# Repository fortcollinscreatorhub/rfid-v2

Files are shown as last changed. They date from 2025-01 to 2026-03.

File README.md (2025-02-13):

# What is this repository?

An RFID reader solution for Fort Collins Creator Hub. The Hub uses RFID readers
on external doors to allow people into the building, and to control
access-to/use-of equipment.

This version of the RFID reader:
* Was developed by Stephen Warren; v1 was by Steve Undy.
* The PCB relies on COTS (Commercial Off-The-Shelf) components where possible,
  to reduce circuit complexity.
* The PCB uses through-hole construction, to make it easier for arbitary people
  to construct.
* Management of the reader is intended to be easier:
  * The PCB has an LCD for status display.
  * WiFi AP mode is enabled when STA mode cannot connect.
  * A web interface is always available for management.
    This may be password protected.
* The software configuration code ("connection manager") is intended to be
  modular and re-usable by other projects. It may be moved into a shared git
  submodule one day.

# How to clone this repository

This project uses git submodules, unfortunately. To clone the repository, run:

```shell
git clone --recurse-submodules https://github.com/fortcollinscreatorhub/rfid-v2
```

If you wish to push back to the github repo, you probably want to clone with
`ssh`, or edit `.git/config` to use ssh URLs after cloning, e.g.:

```shell
git clone --recurse-submodules git@github.com:fortcollinscreatorhub/rfid-v2
```

Or after cloning:

```shell
vi .git/config
```

Even if you clone using the ssh URL, you'll still need to edit the remote
definition for each submodule after the initial clone operation.

# PCB (circuit board)

See the [PCB README](pcb/README.md).

# Software (code)

See the [code README](code/README.md).

# Mounting Boxes

See the [mounting boxes README](mounting-boxes/README.md).

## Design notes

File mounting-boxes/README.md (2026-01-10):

# Mounting box designs

## For equipment

See the [equipment box README](equipment/README.md).

## 3D-printed 

A 3D printed box, as used on our electronics "locker".
See [3D printed box README](3d-printed/README.md).

## For doors

Not yet!

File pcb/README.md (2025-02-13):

# PCB (circuit board)

The PCB was developed using KiCAD 7.0.11 under Ubuntu.

Prototype versions of the PCB were manufactured by
[OSHPARK](https://oshpark.com/). The KiCAD PCB file was uploaded directly, as
opposed to exporting Gerber files, etc.

A production run of the PCB was manufactured by [JLCPCB](https://jlcpcb.com/), using the
Gerber files in directory `gerber-20250210/`.

Read the [Bill Of Materials](BOM.txt).

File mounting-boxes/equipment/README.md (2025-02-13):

# Mounting box for equipment

A design for a box to contain the PCB, and to attach to a piece of equipment.
It's designed to screw into any of:
* A 4" weather-proof box. Good fit. E.g.
  https://www.homedepot.com/p/Commercial-Electric-2-Gang-Metallic-Weatherproof-Box-with-5-3-4-in-Holes-Gray-WDB575G/300846319
* A 2-gang electrical box. Overhangs a bit. E.g.
  https://www.homedepot.com/p/Southwire-4-in-W-x-2-1-8-in-D-Steel-Metallic-2-Gang-Square-Switch-Box-Six-1-2-in-KO-s-Two-3-4-KO-s-and-Four-CKO-s-MGSB-2-UPC/324509229
* A 4" electrical box. Overhangs a bit. E.g.
  https://www.homedepot.com/p/Steel-City-4-in-30-3-cu-in-Metallic-Square-Box-521711234EW-25R/202590467

The design uses [OpenSCAD](https://openscad.org/). Run `render-2d.sh` (under
Linux or WSL2) to render the result.

The layers should be attached using barrel screws (also known as binding
posts, chicago screws, sex screws, and probably other names). Insert these
from the back before mounting to the electrical box. For example:
https://www.amazon.com/dp/B0D5HP8TXD (M4x12mm, 5x20mm).

You could use M3/4 metal inserts or other nuts/bolts if you want. If so,
you'll need to adjust barrel_nut_r/barrel_screw_r in the .scad file to match,
and perhaps also adjust which layers use barrel_nut_holes vs.
barrel_screw_holes.

Layer -1 should be made from thin acrylic; perhaps 1mm, perhaps 3mm. Layers 0,
1, 3, 4 should be made from 3mm acrylic. Layer 2 should be made from 6mm
acrylic to save time, but can also be made from 3mm acrylic if you make more
copies. For layer 2, most likely you will need 2 6mm copies and 1 3mm copy, or
5 3mm copies.

Layer -1 allows the box to seal completely against the box it's screwed to,
since the ends of the barrel nuts stick out a fair way from the box.
Alternatively, you could glue together layers 0 and 1, then move the barrel nut
cutouts to layer 0...

Layers -1 and 0 should be screwed onto the electrical box. Other layers will be
held on by the barrel screws.

The RFID "cage" pieces should be glued into layer 4 using Weldon #4:
https://www.amazon.com/dp/B00TCUJ7A8.

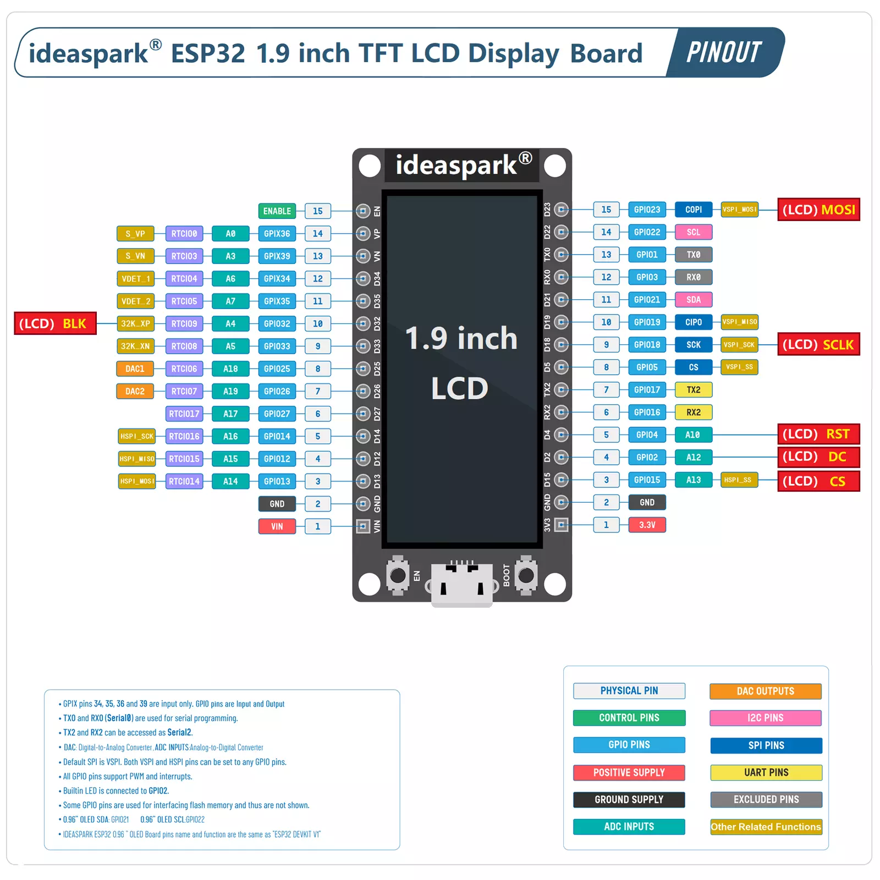
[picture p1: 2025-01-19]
pcb/datasheets-etc/esp32-lcd-190-pinout.webp

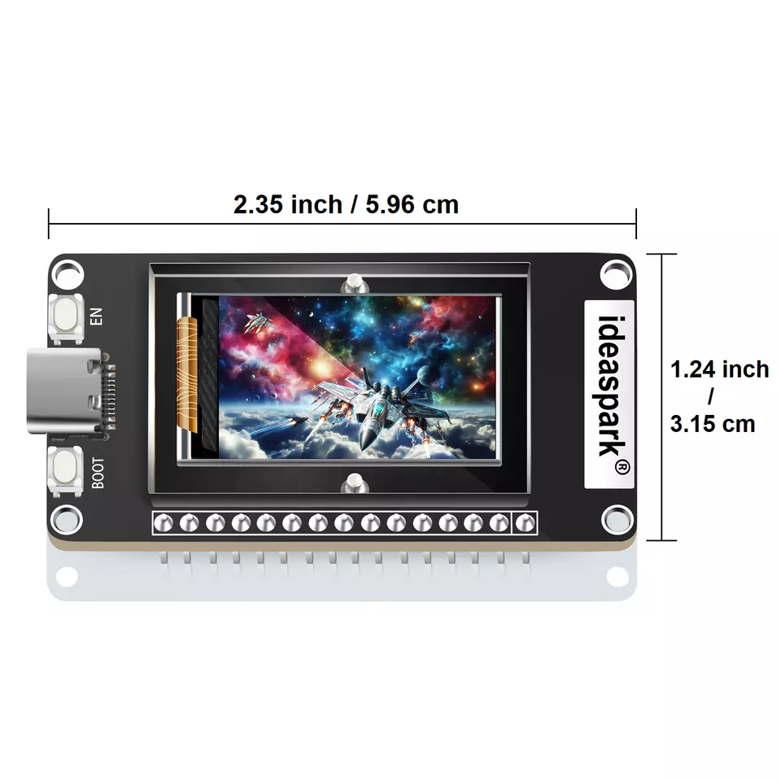
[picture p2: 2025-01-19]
pcb/datasheets-etc/esp32-lcd-114-physical.webp

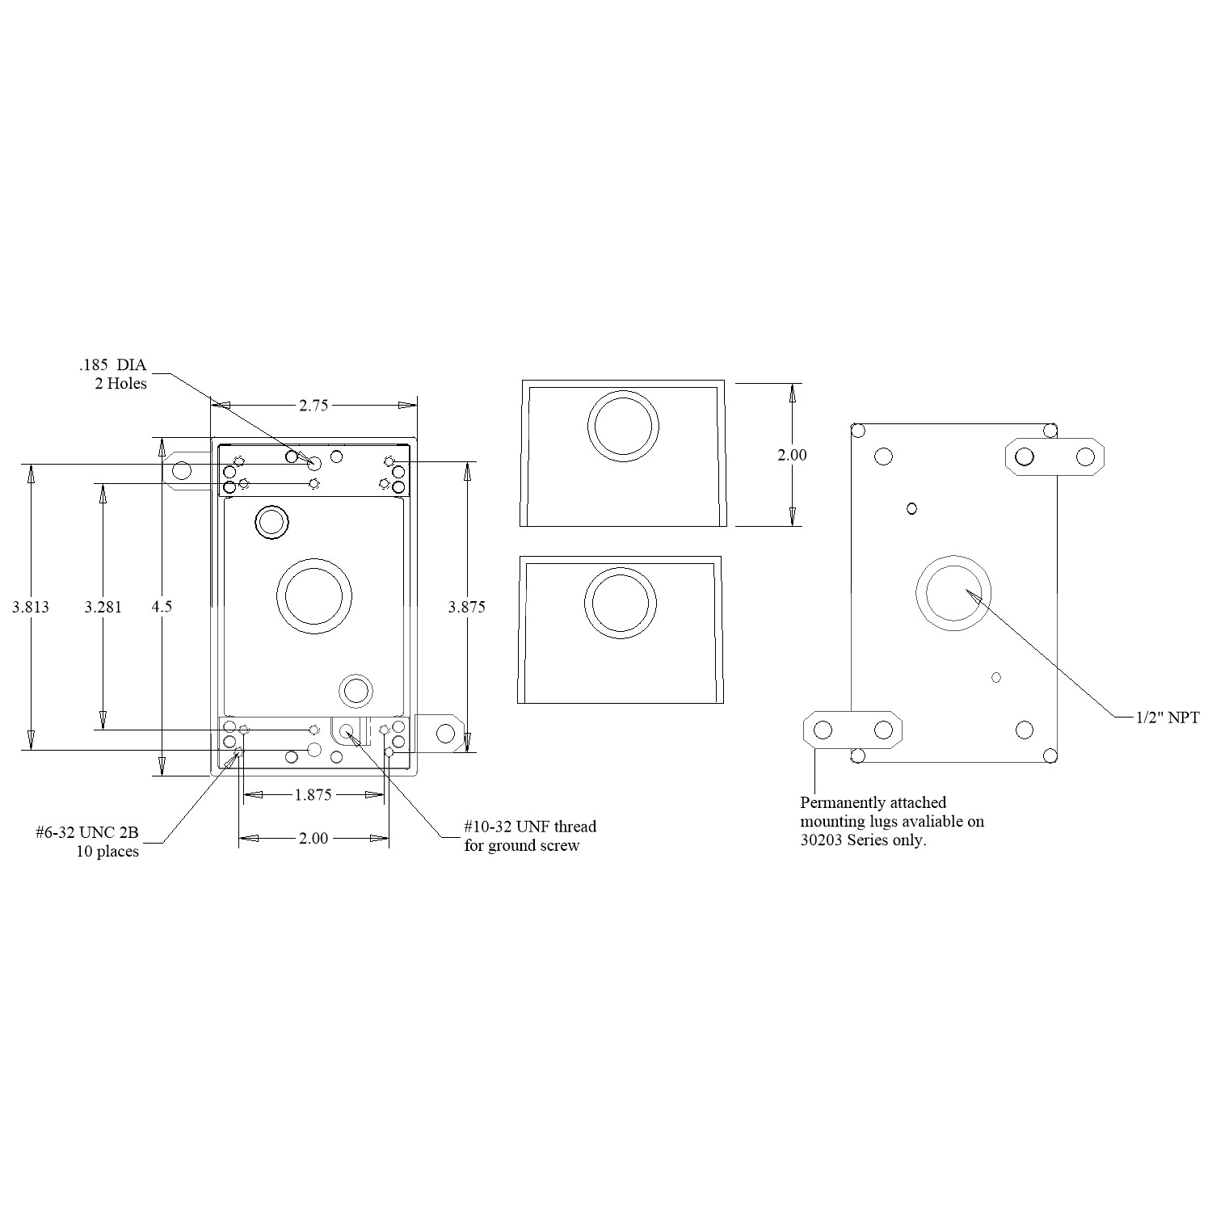
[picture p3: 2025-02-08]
mounting-boxes/electrical-box-drawings/1-gang-waterproof-box-mulberry-metal.jpg

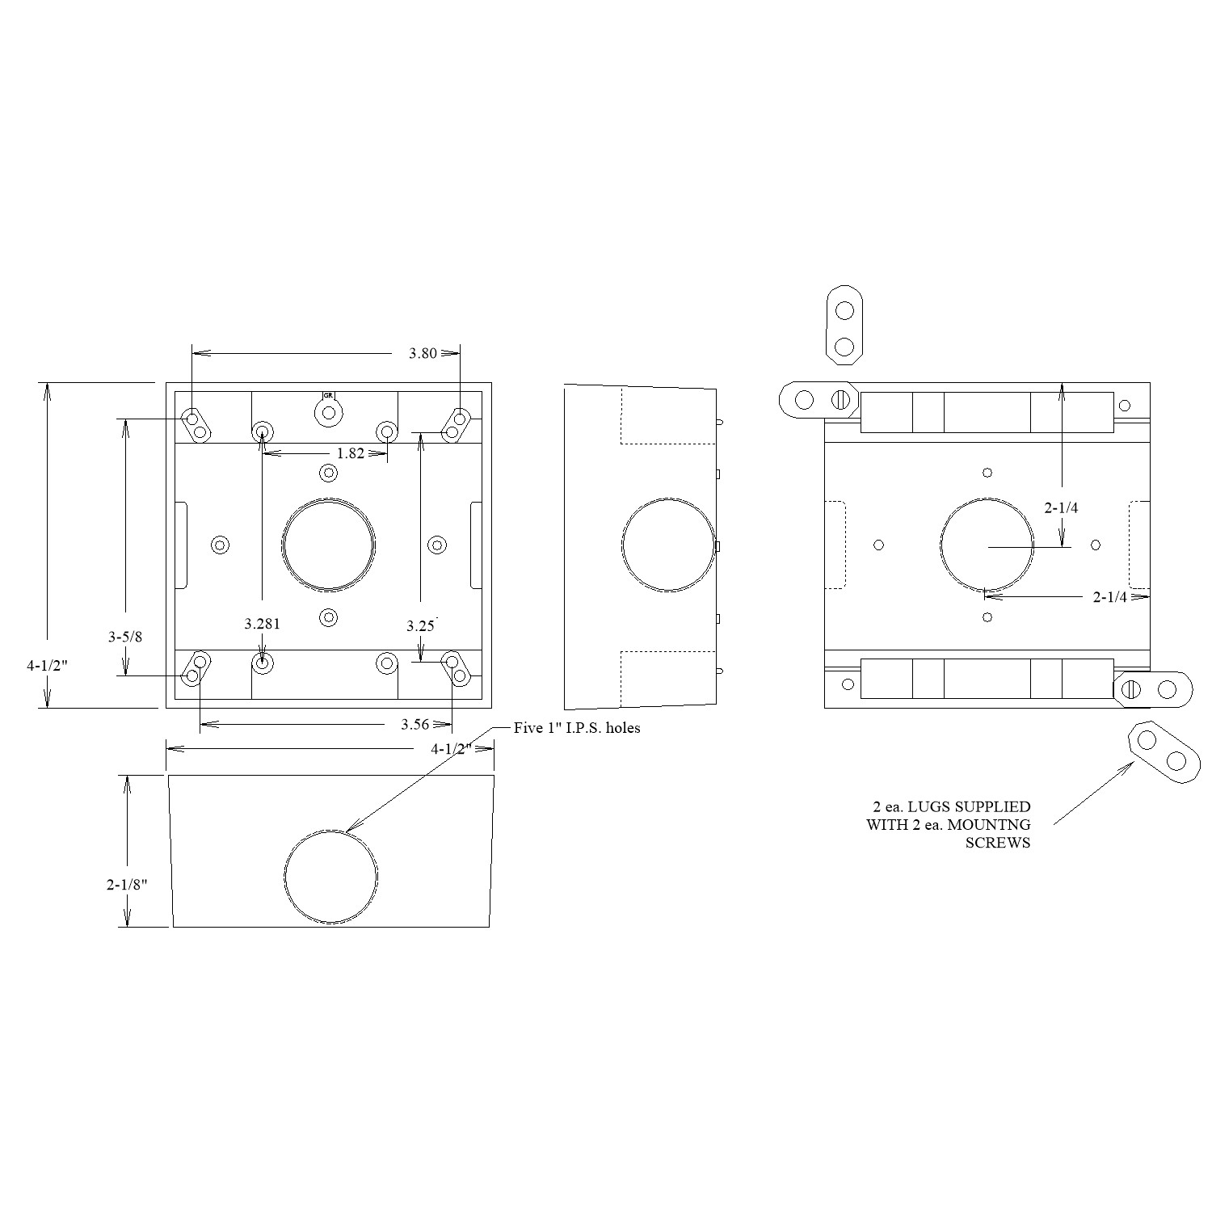
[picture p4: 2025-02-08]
mounting-boxes/electrical-box-drawings/2-gang-waterproof-box-mulberry-metal.jpg

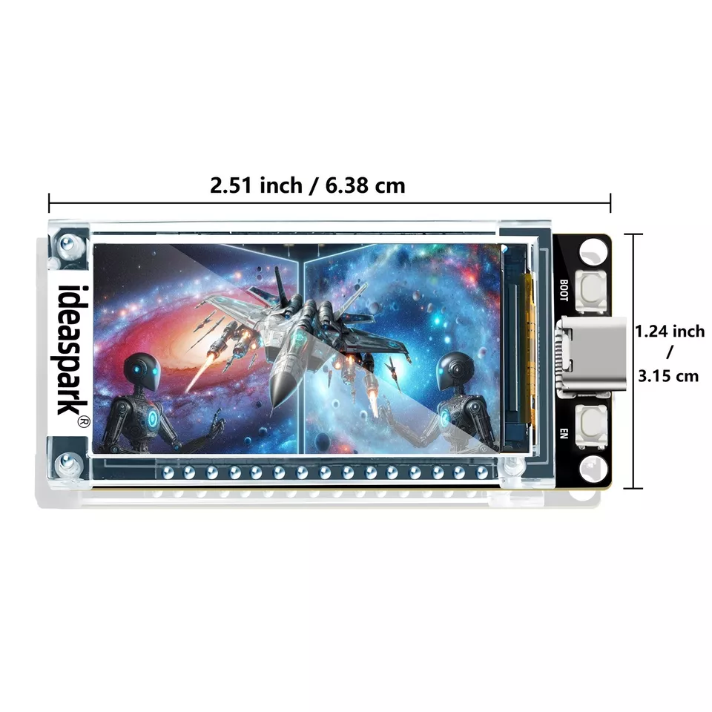
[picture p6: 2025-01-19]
pcb/datasheets-etc/esp32-lcd-190-physical.webp

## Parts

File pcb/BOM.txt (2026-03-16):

U1
    ideaspark® ESP32 Development Board 1.14 inch 135x240 LCD Display,CH340,WiFi+BL
    https://www.ebay.com/itm/176446899270
    ebay seller: https://www.ebay.com/str/ideaspark
    https://www.amazon.com/dp/B0D7S7YQMC
    https://www.aliexpress.us/item/3256807079419720.html

    Alternative (change runtime LCD config):
    ideaspark® ESP32 Development Board 16MB 1.9 in 170x320 LCD Display,CH340,WiFi+BL
    https://www.ebay.com/itm/176425903544
    ebay seller: https://www.ebay.com/str/ideaspark
    https://www.amazon.com/dp/B0D6QXC813
    https://www.aliexpress.us/item/3256806995121078.html

U2
    RDM6300
    HiLetgo RDM6300 125 KHZ EM4100 RFID Card Read Module UART Serial Output for Arduino
    https://www.amazon.com/dp/B00HGB9TOE
    https://www.aliexpress.us/item/3256803401542028.html
    (Many others sell the exact same item on all sites)

U3
    TTGO LILYGO T-Display V1.1
    https://www.amazon.com/dp/B099MPFJ9M
    https://lilygo.cc/en-us/products/t-display?variant=42159376466101

    MELIFE ESP32 Development Board, 16MB Integrated LCD WiFi Kit, 1.14 Inch 135x240 TFT LCD Display,
    https://www.amazon.com/dp/B0FB94RC47

Q1
    PN2222A TO92 (or probably many other NPN BJTs)
    https://www.mouser.com/ProductDetail/onsemi-Fairchild/PN2222ABU?qs=UMEuL5FsraBJOIjLOc%2FtCA%3D%3D
    https://www.digikey.com/en/products/detail/stmicroelectronics/PN2222A/603431 (no longer manfucatured)
    https://www.digikey.com/en/products/detail/onsemi/PN2222ABU/6534
    https://www.amazon.com/dp/B0C1V82313

D1
    1N4001 (or probably many other diodes)
    https://www.mouser.com/ProductDetail/Diotec-Semiconductor/1N4001?qs=OlC7AqGiEDlll8NA510wmA%3D%3D
    https://www.digikey.com/en/products/detail/diotec-semiconductor/1N4001/13164614
    https://www.amazon.com/dp/B0C1V6Y8ND

R1
    1K resistor (any; low power)
    https://www.mouser.com/ProductDetail/SEI-Stackpole/RNMF14FTC1K00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 (1/4W 1%)
    https://www.digikey.com/en/products/detail/stackpole-electronics-inc/RNMF14FTC1K00/2617302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 (1/4W 1%)
    https://www.amazon.com/ALLECIN-Metal-Film-Resistor-Kit/dp/B0CDWVLTM1 (1/4W 1%)
    https://www.amazon.com/ALLECIN-8W-Metal-Film-Resistor/dp/B0C77TM3NR (1/8W 1%

R2
    10K resistor (any; low power)
    https://www.mouser.com/ProductDetail/SEI-Stackpole/RNMF14FTC10K0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 (1/4W 1%)
    https://www.digikey.com/en/products/detail/stackpole-electronics-inc/RNMF14FTC10K0/1683930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 (1/4W 1%)
    https://www.amazon.com/ALLECIN-Metal-Film-Resistor-Kit/dp/B0CDWVLTM1 (1/4W 1%)
    https://www.amazon.com/ALLECIN-8W-Metal-Film-Resistor/dp/B0C77TM3NR (1/8W 1%

R3
    2K2 resistor (any; low power)
    https://www.mouser.com/ProductDetail/SEI-Stackpole/RNMF14FTC2K20?qs=FESYatJ8odLQKVeLgxWICg%3D%3D (1/4W 1%)
    https://www.digikey.com/en/products/detail/stackpole-electronics-inc/RNMF14FTC2K20/2617325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 (1/4W 1%)
    https://www.amazon.com/ALLECIN-Metal-Film-Resistor-Kit/dp/B0CDWVLTM1 (1/4W 1%)
    https://www.amazon.com/ALLECIN-8W-Metal-Film-Resistor/dp/B0C77TM3NR (1/8W 1%

R4
    3K3 resistor (any; low power)
    https://www.mouser.com/ProductDetail/SEI-Stackpole/RNMF14FTC3K30?qs=FESYatJ8odL%252B4KIkrQ9kpA%3D%3D (1/4W 1%)
    https://www.digikey.com/en/products/detail/stackpole-electronics-inc/RNMF14FTC3K30/2617342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 (1/4W 1%)
    https://www.amazon.com/ALLECIN-Metal-Film-Resistor-Kit/dp/B0CDWVLTM1 (1/4W 1%)
    https://www.amazon.com/ALLECIN-8W-Metal-Film-Resistor/dp/B0C77TM3NR (1/8W 1%

K1
    Omron G6S-2
    https://www.mouser.com/ProductDetail/Omron-Electronics/G6S-2-DC5?qs=PuRzBkp%252Brz5TA3zk18rsvQ%3D%3D
    https://www.digikey.com/en/products/detail/omron-electronics-inc-emc-div/G6S-2-DC5/333982
    https://www.amazon.com/dp/B082Z3K9BG

J1
    0.2"/5mm PCB mount screw terminal block, 2-pin
    https://www.mouser.com/ProductDetail/Phoenix-Contact/5452257?qs=iCzJi%2FIZBF6%2Fj2I2DfTHZA%3D%3D
    https://www.digikey.com/en/products/detail/phoenix-contact/5452257/4391130?s=N4IgTCBcDaIKwBY5jHA7CAugXyA
    https://www.amazon.com/gp/product/B0D1GMMTZ5

J2
    0.2"/5mm PCB mount screw terminal block, 3-pin
    https://www.mouser.com/ProductDetail/Phoenix-Contact/5452258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
    https://www.digikey.com/en/products/detail/phoenix-contact/5452258/4391131
    https://www.amazon.com/gp/product/B0D1GMMTZ5

J3
    No part; solder in the coil that comes with RDM6300.

Power supply for the RFID reader
    Meanwell APV-25-5 (25W 5V) (rather large.)
    https://www.amazon.com/dp/B00HKJ6JKE
    Meanwell APV-12-5 (12W 5V) (smaller, cheaper, and seems to work fine.)
    https://www.amazon.com/dp/B00FRBSI2E

Power supply for 12V external devices
    Meanwell APV-25-12 (25W 12V)
    https://www.amazon.com/Constant-Voltage-Switching-Supply-2100mA/dp/B00MEJTTCU

SSR for device control
    CG Solid State Relay SSR-25DA DC to AC Input 3-32VDC To Output 24-480VAC 25A Single Phase Plastic Cover…
    https://www.amazon.com/dp/B08GPJ1V2J
    (or many others)

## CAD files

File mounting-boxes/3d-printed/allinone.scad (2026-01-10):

// ==========================================
//    RFID - V2 Enclosure w/ Buck Converter
// ==========================================
// 
// This script generates a custom 3D-printable enclosure for an RFID reader,
// designed to house a controller PCB, buck converter, and DC jack in a 
// compact, modular base.
//
// All the pieces are:
// - The base. 
// -- Uses clip tabs to hold down the controller board since it doesn't have mounting holes 
// -- Screw posts for buck converter
// - The lid. W/ opening for LCD and recessed cavity for RFID antenna. 
// - A cover for the RFID antenna mounted inside the lid. Should glue over that slot.
// - A cover for the banana jack housing. I'm using the one that came w/ the power brick.
// - An external cover for the male end of DC jack that plugs into that.
// - A plug (need 2x) to cover the boot and reset buttons on the controller board

$fn = 60;

// This can help isolate rendering different modules in case you want to 
// export STL separately. If you choose "all" then everything will be rendered
// at once and you can split apart in slicer.
//
part_to_show = "all"; // Options: "base", "lid", "dc_lid", "jack_cover", "antenna_cover", "cable_clamp", "plugs", "inserts", "all", "closed", "cutaway"

// The FCCH RFID-V2 main board. Snap toggles hold it in place
pcb_width = 45.2;
pcb_length = 90.2;
pcb_thickness = 1.6;

// LM2596 generic Buck Converter
buck_width = 43;      
buck_length = 21;     
buck_hole_dist_x = 31;
buck_hole_dist_y = 16; 
buck_hole_dia = 2.0;
buck_elevation = 5;

// DC Jack Internal Compartment to securely hold the jack in place
//
dc_comp_inner_w = 15;  
dc_comp_inner_l = 33;  
dc_jack_hole = 8;   
dc_slot_size = 10.5;   

// Main board USB opening
enable_usb_slot = true;
usb_slot_width = 12;   
usb_slot_height = 6;   
usb_z_adjust = 5;    

// Layout and spacing
side_padding_x = 9.0; 
pcb_vertical_margin = 1.0; 
col_spacing = 8;        
row_spacing = 8;     
dc_jack_height = 12.25; 

// Positioning parameters for rfid antenna within lid
rfid_ant_w = 47.5; rfid_ant_l = 36.5; rfid_ant_depth = 2.25;
rfid_pos_x = 43; rfid_pos_y = 21; 

// Cutouts for main board lcd, boot and reset buttons
lcd_width = 25; lcd_height = 38;
button_diameter = 6; button_spacing = 16.5;
lcd_pos_x = 15.8; lcd_pos_y = 20;
buttons_center_x = lcd_pos_x + (lcd_width / 2); 
buttons_center_y = 11;

// Tabs holding main pc board in base
enable_mounting_tabs = true;
tab_protrusion = 10;
tab_width = 15;
tab_hole_dia = 4.5;
tab_thickness = 3.0;

// Various mounting helpers
post_diameter = 8;
pin_diameter = 5.2;
screw_hole_inner = 2.8;
screw_hole_outer = 3.4;
screw_thread_depth = 12;

// Cover for external dc power supply jack in comboniation with Jack Cover below
lock_pin_dia = 2.4;       
lock_travel_y = 3.5;
boss_w = dc_jack_hole + 10; 
// boss_h calculated in Engine
boss_depth = 4.0;         
lock_tolerance = 0.3;

// Jack Cover Settings
jack_plug_length = 26;
jack_plug_dia = 10;
jack_wire_dia = 5;
cover_wall_t = 1.6;

// Some generic dimensions
wall_thickness = 2.4;
lid_thickness = 4.0; 

internal_wall_t = 1.6; 
pcb_elevation = 5;
tolerance = 0.5;
lip_depth = 2.0;
internal_height = 18; // [UPDATED] Height reduced as requested
corner_radius = 3.0;

// DC Lid Settings
dc_lid_cap_thickness = 2.0;
dc_lid_plug_depth = 2.4; 

// Logo Insert Settings
logo_tolerance = 0.1; 

// ==========================================
//            Derived Dimensions
// ==========================================

usb_slot_x_center = wall_thickness + side_padding_x + 15.5;

// Calculate Jack Z Height Globally
jack_center_z = wall_thickness + 1.25 + (dc_jack_hole / 2);

// Calculate Boss Height to reach from Z=0 to Top Clearance
boss_h = jack_center_z + (dc_jack_hole / 2) + 3.0;

// Calculate Base Requirements
col1_w = pcb_width;
col1_l = pcb_length;

buck_rot_w = buck_length; 
buck_rot_l = buck_width;  

// DC Width (Includes LEFT and RIGHT internal walls)
dc_outer_w = dc_comp_inner_w + (internal_wall_t * 2);
dc_outer_l = dc_comp_inner_l + internal_wall_t;

// Total length of DC walls including the extension to front wall
dc_wall_total_l = dc_outer_l + pcb_vertical_margin;

col2_w = max(buck_rot_w, dc_outer_w);
col2_l = dc_outer_l + row_spacing + buck_rot_l;

req_inner_w = side_padding_x + col1_w + col_spacing + col2_w + side_padding_x;
base_req_inner_l = pcb_vertical_margin + max(col1_l, col2_l) + pcb_vertical_margin;

// 3. Final Box Dimensions
max_comp_x = max(rfid_pos_x + rfid_ant_w, lcd_pos_x + lcd_width, buttons_center_x + button_spacing/2 + button_diameter/2);
max_comp_y = max(rfid_pos_y + rfid_ant_l, lcd_pos_y + lcd_height, buttons_center_y + button_diameter/2);
lid_req_outer_w = max_comp_x + wall_thickness;
lid_req_outer_l = max_comp_y + wall_thickness;

final_outer_w = max(req_inner_w + (wall_thickness*2), lid_req_outer_w);
final_outer_l = max(base_req_inner_l + (wall_thickness*2), lid_req_outer_l); 

final_inner_w = final_outer_w - (wall_thickness*2);
final_inner_l = final_outer_l - (wall_thickness*2);


// ==========================================
//            All the modules
// ==========================================

module rounded_rect(w, l, h, r) {
    hull() {
        translate([r, r, 0]) cylinder(h=h, r=r);
        translate([w-r, r, 0]) cylinder(h=h, r=r);
        translate([w-r, l-r, 0]) cylinder(h=h, r=r);
        translate([r, l-r, 0]) cylinder(h=h, r=r);
    }
}

module pcb_snap_latch() {
    clip_w = 10; clip_t = 1.6; latch_h = pcb_elevation + pcb_thickness + 1.2;
    translate([-clip_t, -clip_w/2, 0]) cube([clip_t, clip_w, latch_h]);
    translate([0, -clip_w/2, latch_h]) rotate([-90, -90, 0]) linear_extrude(clip_w) polygon([[0,0], [0, -2], [1.5, -2], [0.8, 0], [0, 0.5]]);
}

module mounting_tab(angle_rotation) {
    gusset_height = internal_height * 0.6;
    side_gusset_thickness = 2.4; 
    rotate([0,0,angle_rotation]) {
        difference() {
            union() {
                hull() {
                    translate([-tab_width/2, 0, 0]) cube([tab_width, 0.1, tab_thickness]);
                    translate([0, tab_protrusion, 0]) cylinder(h=tab_thickness, d=tab_width);
                }
                hull() {
                    translate([-tab_width/2, 0, tab_thickness]) cube([side_gusset_thickness, 0.1, gusset_height]);
                    translate([-tab_width/2, tab_protrusion, tab_thickness]) cube([side_gusset_thickness, 0.1, 0.1]);
                }
                hull() {
                    translate([tab_width/2 - side_gusset_thickness, 0, tab_thickness]) cube([side_gusset_thickness, 0.1, gusset_height]);
                    translate([tab_width/2 - side_gusset_thickness, tab_protrusion, tab_thickness]) cube([side_gusset_thickness, 0.1, 0.1]);
                }
            }
            translate([0, tab_protrusion, -1]) cylinder(h=tab_thickness + 2, d=tab_hole_dia);
        }
    }
}

module dc_compartment_lid() {
    fit_tol = 0.15; 
    
    // Tab Settings
    tab_len = 15;
    tab_dep = 5.25;
    tab_wid = 2.5;

    union() {
        // 1. The Main Cap
        cube([dc_outer_w, dc_wall_total_l, dc_lid_cap_thickness]);
        
        // 2. The Plug
        translate([internal_wall_t + fit_tol, internal_wall_t + fit_tol, -dc_lid_plug_depth]) {
            cube([
                dc_comp_inner_w - (fit_tol*2), 
                (dc_wall_total_l - (internal_wall_t*2)) - (fit_tol*2), 
                dc_lid_plug_depth
            ]);
        }
        
        // 3. Inside Top Edge Tab
        translate([
            (dc_outer_w - tab_len) / 2,     
            dc_wall_total_l - internal_wall_t - tab_wid - fit_tol, 
            -tab_dep                        
        ])
        cube([tab_len, tab_wid, tab_dep]);
    }
}


module jack_cover() {
    // 1. Calculate Internal Dimensions
    inner_w = boss_w + (lock_tolerance * 2);
    inner_h = boss_h + (lock_tolerance * 2);
    
    // 2. Calculate Depth
    internal_depth = jack_plug_length + boss_depth;
    
    // 3. Calculate External Dimensions
    cover_w = inner_w + (cover_wall_t * 2);
    cover_l = internal_depth + cover_wall_t; // Add thickness for the back wall
    cover_h_dim = inner_h + cover_wall_t;    // Add thickness for the top wall

    // Pin Positions 
    pin_z = 3.0; 
    pin_y_offset = boss_depth / 2; 

    difference() {
        // Main Block
        cube([cover_w, cover_l, cover_h_dim]);
        
        // Internal Cavity ("The Garage")
        translate([cover_wall_t, -0.1, -0.1])
            cube([inner_w, internal_depth + 0.1, inner_h]);
            
        // Wire Slot
        translate([(cover_w/2) - (jack_wire_dia/2), internal_depth - 2, -0.1])
            cube([jack_wire_dia, cover_wall_t + 10, inner_h]);
    }
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

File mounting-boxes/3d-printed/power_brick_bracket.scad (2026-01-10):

// A mounting cover for a 12v dc power brick that's used to power the RFID latch locker
// Printed w/ PLA is fine probably. We'll see.
//

// Power Supply Dimensions
psu_length = 120.5;
psu_width  = 51.5;
psu_height = 35.0;

// Housing settings
wall_thick = 2.4;       
tolerance  = 1.0; 
corner_radius = 3.0;    // Radius of the outside vertical edges

// Mounting Tab Settings
mount_hole_dia = 3.5;       // Screw shaft size
head_dia       = 6;       // Screw head size (Counterbore)
head_depth     = 5.0;       // Depth of screw head recess
tab_stick_out  = 14.0;      // How far the tab extends out
tab_length     = 30.0;      // Width of the tab along the wall

// Input Power Cord Slot (Centered)
slot1_width = 17.0;
slot1_depth = 22.0;    

// DC Output Cord Slot (Offset)
slot2_width = 14.0;
slot2_depth = 20.0;
slot2_offset = 7;    

// Ventilation
vent_width = 4;
vent_gap = 4;

// --- Calculated Values ---
inner_l = psu_length + tolerance;
inner_w = psu_width + tolerance;
inner_h = psu_height + tolerance; 

outer_l = inner_l + (wall_thick * 2);
outer_w = inner_w + (wall_thick * 2);
outer_h = inner_h + wall_thick; 

// --- Main Render ---

difference() {
    union() {
        // 1. Main Housing Body (Rounded)
        translate([0, 0, outer_h/2])
            rounded_box(outer_l, outer_w, outer_h, corner_radius);
            
        // 2. Gusseted Tabs
        generate_pocket_tabs();
    }

    // 3. Hollow out the inside (Sharp corners for the brick)
    translate([-inner_l/2, -inner_w/2, -1])
        cube([inner_l, inner_w, inner_h + 1]);

    // 4. Slot 1: Power Cord
    translate([-outer_l/2 - 5, -slot1_width/2, -1])
        cube([wall_thick + 10, slot1_width, slot1_depth + 1]);

    // 5. Slot 2: DC Out
    // MIRRORED: Measured from the -Y edge
    translate([outer_l/2 - wall_thick - 5, -(inner_w/2) + slot2_offset, -1])
        cube([wall_thick + 10, slot2_width, slot2_depth + 1]);

    // 6. Rounded Vents
    generate_side_vents();
    generate_top_vents();
}

// --- Modules ---

module rounded_box(len, wid, hei, rad) {
    x_pos = (len/2) - rad;
    y_pos = (wid/2) - rad;
    
    hull() {
        translate([-x_pos, -y_pos, -hei/2]) cylinder(r=rad, h=hei, $fn=50);
        translate([x_pos, -y_pos, -hei/2])  cylinder(r=rad, h=hei, $fn=50);
        translate([-x_pos, y_pos, -hei/2])  cylinder(r=rad, h=hei, $fn=50);
        translate([x_pos, y_pos, -hei/2])   cylinder(r=rad, h=hei, $fn=50);
    }
}

module generate_pocket_tabs() {
    translate([0, -outer_w/2, 0]) 
        make_pocket_tab();

    translate([0, outer_w/2, 0]) 
        rotate([0,0,180]) make_pocket_tab();
}

module make_pocket_tab() {
    sink = 2.0; 
    gusset_height = tab_stick_out;
    base_h = 2.0; 
    
    difference() {
        // 1. Solid Ramp
        hull() {
            translate([-tab_length/2, -tab_stick_out, 0])
                cube([tab_length, tab_stick_out + sink, base_h]); 
            
            translate([-tab_length/2, sink, gusset_height + base_h])
                cube([tab_length, 0.1, 0.1]);
        }
        
        // 2. Screw Shaft Slot
        hull() {
            translate([-2, -tab_stick_out/2, -1])
                cylinder(h=gusset_height + 5, d=mount_hole_dia, $fn=30);
            translate([2, -tab_stick_out/2, -1])
                cylinder(h=gusset_height + 5, d=mount_hole_dia, $fn=30);
        }

        // 3. Counterbore Pocket
        hull() {
            translate([-2, -tab_stick_out/2, base_h + head_depth]) 
                cylinder(h=gusset_height, d=head_dia, $fn=30);
            translate([2, -tab_stick_out/2, base_h + head_depth]) 
                cylinder(h=gusset_height, d=head_dia, $fn=30);
            
            translate([-2, -tab_stick_out/2, head_depth])
                cylinder(h=1, d=head_dia, $fn=30);
            translate([2, -tab_stick_out/2, head_depth])
                cylinder(h=1, d=head_dia, $fn=30);
        }
    }
}

module generate_side_vents() {
    start_height = tab_stick_out + 4; 
    safe_length = inner_l - (2 * corner_radius) - 10;
    
    count = floor(safe_length / (vent_width + vent_gap));
    start_x = -((count * (vent_width + vent_gap)) / 2) + (vent_width/2);
    
    r = vent_width / 2;
    h_vent = inner_h - start_height - 5;
    
    for (i = [0 : count-1]) {
        x_pos = start_x + (i * (vent_width + vent_gap));
        
        // Use hull of 2 cylinders to make a pill shape (vertical slot)
        // Oriented to cut through Y axis
        translate([x_pos + r, 0, 0]) { // Shift X by radius to center the hull
            hull() {
                // Bottom of slot
                translate([0, -outer_w/2 - 5, start_height + r])
                    rotate([-90, 0, 0])
                    cylinder(r=r, h=outer_w + 10, $fn=20);
                
                // Top of slot
                translate([0, -outer_w/2 - 5, start_height + h_vent - r])
                    rotate([-90, 0, 0])
                    cylinder(r=r, h=outer_w + 10, $fn=20);
            }
        }
    }
}

module generate_top_vents() {
    safe_length = inner_l - (2 * corner_radius) - 10;
    
    count = floor(safe_length / (vent_width + vent_gap));
    start_x = -((count * (vent_width + vent_gap)) / 2) + (vent_width/2);
    
    r = vent_width / 2;
    len_vent = inner_w - 10;
    
    for (i = [0 : count-1]) {
        x_pos = start_x + (i * (vent_width + vent_gap));
        
        // Use hull of 2 cylinders to make a pill shape (horizontal slot)
        // Oriented to cut through Z axis
        translate([x_pos + r, 0, 0]) {
            hull() {
                // Front end (-Y)
                translate([0, -inner_w/2 + 5 + r, outer_h - wall_thick - 1])
                    cylinder(r=r, h=wall_thick + 2, $fn=20);
                
                // Back end (+Y)
                translate([0, -inner_w/2 + 5 + len_vent - r, outer_h - wall_thick - 1])
                    cylinder(r=r, h=wall_thick + 2, $fn=20);
            }
        }
    }
}

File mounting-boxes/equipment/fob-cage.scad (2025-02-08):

// Copyright 2025 Stephen Warren <swarren@wwwdotorg.org>
// Reverse-engineered from a design by Steve Undy
//
// Permission is hereby granted, free of charge, to any person obtaining a
// copy of this software and associated documentation files (the "Software"),
// to deal in the Software without restriction, including without limitation
// the rights to use, copy, modify, merge, publish, distribute, sublicense,
// and/or sell copies of the Software, and to permit persons to whom the
// Software is furnished to do so, subject to the following conditions:
//
// The above copyright notice and this permission notice shall be included in
// all copies or substantial portions of the Software.
//
// THE SOFTWARE IS PROVIDED "AS IS", WITHOUT WARRANTY OF ANY KIND, EXPRESS OR
// IMPLIED, INCLUDING BUT NOT LIMITED TO THE WARRANTIES OF MERCHANTABILITY,
// FITNESS FOR A PARTICULAR PURPOSE AND NONINFRINGEMENT.  IN NO EVENT SHALL
// THE AUTHORS OR COPYRIGHT HOLDERS BE LIABLE FOR ANY CLAIM, DAMAGES OR OTHER
// LIABILITY, WHETHER IN AN ACTION OF CONTRACT, TORT OR OTHERWISE, ARISING
// FROM, OUT OF OR IN CONNECTION WITH THE SOFTWARE OR THE USE OR OTHER
// DEALINGS IN THE SOFTWARE.

// Configuration:
epsilon = 0.001;
cage_thickness = 3.108;
cage_side_fingers = 7;
cage_side_units = (cage_side_fingers * 2) - 1;
cage_finger_joint_total_len = 85;
cage_side_h = 16;
cage_unit_len = cage_finger_joint_total_len / cage_side_units;
cage_top_w = 18;
cage_side_finger_joint_offset = 24;
cage_side_angle = 56;
cage_cc_w = 65;
cage_cc_h = 1;
cage_face_to_rfid_hole_scale = 0.45;
cage_face_to_rfid_hole_len = 37;
cage_face_slot_w = 6;
// Should really calculate this as distance to the center of rfid hole...
cage_face_slot_h = 50;
cage_face_slot_chamfer_scale = 0.94;

// Derived:
cage_side_half_angle = cage_side_angle / 2;
cage_cage_face_body_dy = cage_thickness / 2;
// t=o/a, a=o/tan, angle=cage_side_angle/2 (triangle-mid-angle)
cage_cage_face_body_dx = cage_cage_face_body_dy / tan(cage_side_half_angle);
cage_cage_face_body_dxy = [cage_cage_face_body_dx, cage_cage_face_body_dy];
cage_face_rfid_dxy = cage_cage_face_body_dxy / norm(cage_cage_face_body_dxy) * cage_face_to_rfid_hole_len;

module cage_unit() {
    translate([-epsilon/2, -epsilon/2]) {
        square(size=[cage_unit_len + epsilon, cage_thickness + epsilon], center=false);
    }
}

module cage_mount_holes_one_edge() {
    translate([cage_side_finger_joint_offset, 0]) {
        cage_unit();
        translate([cage_finger_joint_total_len - cage_unit_len, 0]) {
            cage_unit();
        }
    }
}

module cage_mount_holes() {
    rotate(90-cage_side_half_angle) {
        translate([0, -cage_thickness/2]) cage_mount_holes_one_edge();
        rotate([0, 0, cage_side_angle]) {
            translate([0, -cage_thickness/2]) cage_mount_holes_one_edge();
        }
    }
}

module cage_side_body() {
    square(size=[cage_finger_joint_total_len, cage_side_h], center=false);
}

module cage_fingers() {
    for (i=[0:cage_side_fingers - 1]) {
        translate([cage_unit_len * 2 * i, 0]) {
            cage_unit();
        }
    }
}

module cage_fingers_inverted() {
    difference() {
        square(size=[cage_finger_joint_total_len, cage_thickness], center=false);
        cage_fingers();
    }
}

cage_side_inter_hole_cutout_len = cage_finger_joint_total_len - (2 * cage_unit_len);
module cage_side_inter_hole_cutout() {
    square(size=[cage_side_inter_hole_cutout_len, cage_thickness + epsilon], center=false);
}

module cage_side_cage_cc_slot_cutout() {
    square(size=[cage_cc_w, cage_cc_h + epsilon], center=false);
}

module cage_side() {
    ihc_dx = cage_unit_len;
    ihc_dy = cage_side_h - cage_thickness;
    cage_cc_dx = (cage_finger_joint_total_len - cage_cc_w) / 2;
    cage_cc_dy = cage_side_h - (cage_thickness + cage_cc_h);
    difference() {
        cage_side_body();
        translate([0, -epsilon]) cage_fingers_inverted();
        translate([ihc_dx, ihc_dy]) cage_side_inter_hole_cutout();
        translate([cage_cc_dx, cage_cc_dy]) cage_side_cage_cc_slot_cutout();
    }
}

module cage_top() {
    square(size=[cage_top_w, cage_side_h - (2 * cage_thickness)], center=false);
}

module cage_face_body() {
    side_len = cage_side_finger_joint_offset + cage_finger_joint_total_len - cage_cage_face_body_dx;
    hull()  {
        square([side_len, epsilon], center=false);
        rotate(cage_side_angle) square([side_len, epsilon], center=false);
    }
}

module cage_face_fob_cutout() {
    translate(cage_face_rfid_dxy) {
        scale([cage_face_to_rfid_hole_scale, cage_face_to_rfid_hole_scale, 1]) {
            cage_face_body();
        }
    }
}

module cage_face_slot_cutout() {
    rotate(cage_side_half_angle) {
        translate([0, -cage_face_slot_w / 2]) {
            square(size=[cage_face_slot_h, cage_face_slot_w], center=false);
        }
    }
}

module cage_face_slot_chamfer() {
    adj_over_hypot = cage_cage_face_body_dxy[0] / norm(cage_cage_face_body_dxy);
    s = (cage_side_finger_joint_offset - cage_cage_face_body_dx) * adj_over_hypot * cage_face_slot_chamfer_scale * 2;
    rotate(cage_side_half_angle + 45) {
        square(size=[s, s], center=true);
    }
}

module cage_face_bottom_cutoff() {
    adj_over_hypot = cage_cage_face_body_dxy[0] / norm(cage_cage_face_body_dxy);
    s = (cage_side_finger_joint_offset - cage_cage_face_body_dx) * adj_over_hypot * 2;
    rotate(cage_side_half_angle) {
        square(size=[s, s], center=true);
    }
}

module cage_face_fingers() {
    translate([cage_side_finger_joint_offset, -cage_thickness/2]) cage_fingers_inverted();
    rotate([0, 0, cage_side_angle]) {
        translate([cage_side_finger_joint_offset, -cage_thickness/2]) cage_fingers_inverted();
    }
}

module cage_face() {
    rotate(90-cage_side_half_angle) {
        translate(cage_cage_face_body_dxy) {
            difference() {
                cage_face_body();
                cage_face_fob_cutout();
                cage_face_slot_cutout();
                cage_face_slot_chamfer();
                cage_face_bottom_cutoff();
            }
        }
        cage_face_fingers();
    }
}

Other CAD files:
mounting-boxes/equipment/mounting.scad
mounting-boxes/equipment/render-2d.scad
mounting-boxes/equipment/render-3d.scad

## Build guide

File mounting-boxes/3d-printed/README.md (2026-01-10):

These two designs are OpenSCAD mounting box for the RFID controller and a Buck Converter.

I printed them in PLA and that should work but if the power brick generates too much heat may need to reprint in PETG or other.

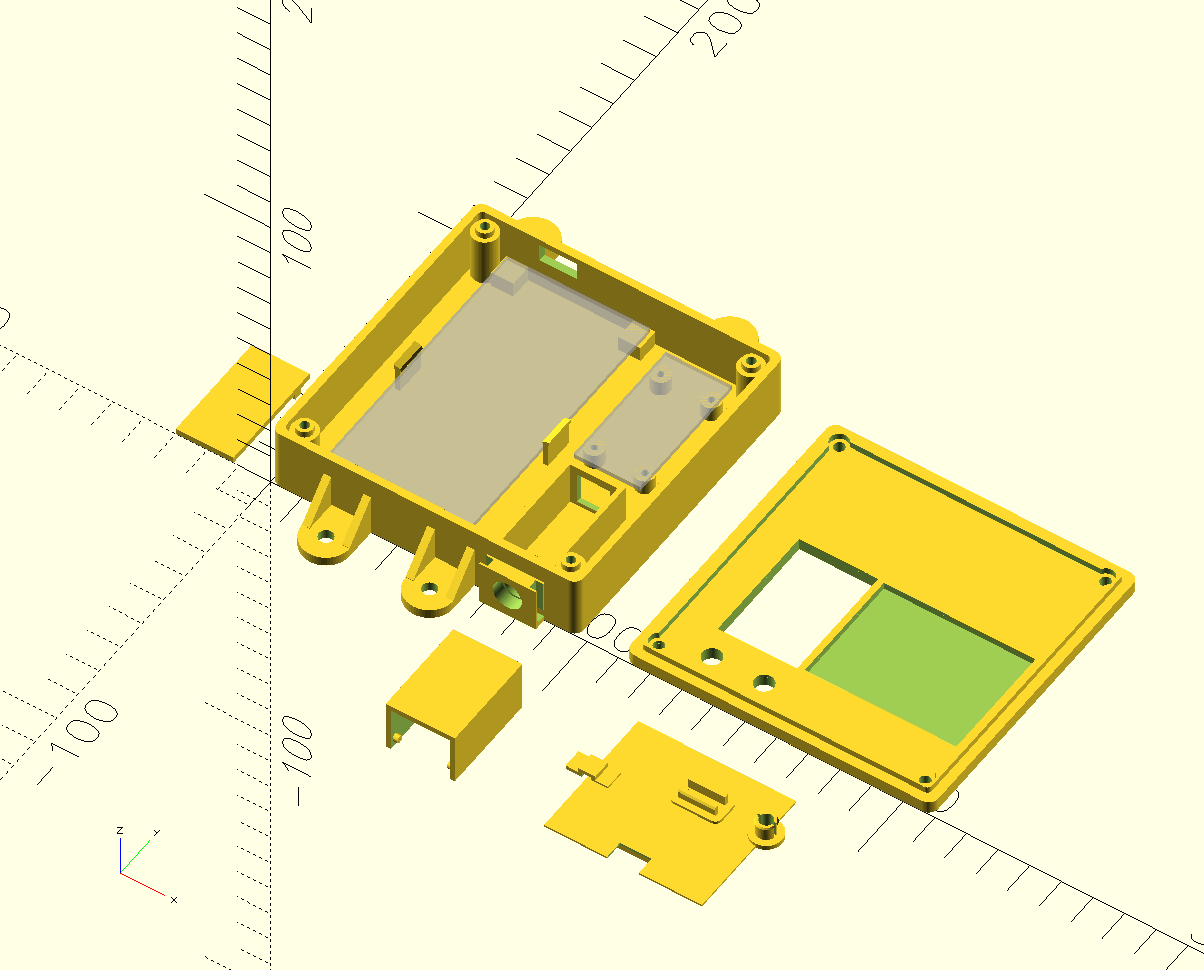
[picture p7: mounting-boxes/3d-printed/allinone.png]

Figure 1. The OpenSCAD render

Here's the printed cases. The controller board snaps into place and has offset posts holding it off the bottom of the case. The Buck Converter is screwed in with 2.5mm screws. The female jack is mounted inside the base and a lid press fits to hold that in place. The RFID antenna sits in a cavity in the lid. There's a cover that's glued on to hold it in place. The model also includes plugs for the controller USB-C port and RST/BOOT buttons.


Figure 2. 3D-Printed CASE with electronics Mounted

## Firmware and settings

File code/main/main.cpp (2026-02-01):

// Copyright 2024-2026 Stephen Warren <swarren@wwwdotorg.org>
// SPDX-License-Identifier: MIT

#include <inttypes.h>
#include <string.h>
#include <stdio.h>
#include <sys/param.h>
#include <sys/poll.h>
#include <sys/socket.h>
#include <unistd.h>

#include <esp_event.h>
#include <esp_log.h>
#include <nvs.h>
#include <nvs_flash.h>

#include "fcch_acl_client/acl_client.h"
#include "fcch_connmgr/cm.h"
#include "fcch_rfid/rfid.h"
#include "lcd.h"
#include "momentary.h"
#include "mqtt.h"
#include "relay.h"

enum main_event {
    MAIN_EVENT_RFID_PRESENT,
    MAIN_EVENT_RFID_ABSENT,
};

static const char *TAG = "main";

static esp_event_loop_handle_t main_event_loop;
ESP_EVENT_DEFINE_BASE(MAIN_EVENT);

static void main_rfid_present(uint32_t rfid) {
    ESP_ERROR_CHECK(esp_event_post_to(main_event_loop,
        MAIN_EVENT, MAIN_EVENT_RFID_PRESENT,
        &rfid, sizeof(rfid), 10 / portTICK_PERIOD_MS));
}

static void main_rfid_absent() {
    ESP_ERROR_CHECK(esp_event_post_to(main_event_loop,
        MAIN_EVENT, MAIN_EVENT_RFID_ABSENT,
        NULL, 0, 10 / portTICK_PERIOD_MS));
}

static void main_event_handler(
    void *arg,
    esp_event_base_t event_base,
    int32_t event_id,
    void *event_data
) {
    if (event_base != MAIN_EVENT) {
        ESP_LOGE(TAG, "main_event_handler: event_base != MAIN_EVENT");
        return;
    }

    switch (event_id) {
        case MAIN_EVENT_RFID_PRESENT: {
            uint32_t rfid = *(uint32_t *)event_data;
            ESP_LOGI(TAG, "MAIN_EVENT_RFID_PRESENT: %lu", rfid);
            // FIXME: Might want our own event loop task since
            // acl_client_check_id might take a while.
            // rfid_init should take an event loop handle to post to.
            bool allowed;
            esp_err_t err = acl_client_check_id(rfid, &allowed);
            if (err != ESP_OK) {
                ESP_LOGW(TAG, "ACL check error: %d", err);
                lcd_on_rfid_err(rfid);
                mqtt_on_rfid_err(rfid);
                break;
            }
            ESP_LOGI(TAG, "ACL check: %d", (int)allowed);
            if (allowed) {
                relay_on_rfid_ok();
                lcd_on_rfid_ok(rfid);
                mqtt_on_rfid_ok(rfid);
            } else {
                lcd_on_rfid_bad(rfid);
                mqtt_on_rfid_bad(rfid);
            }
            break;
        }
        case MAIN_EVENT_RFID_ABSENT: {
            ESP_LOGI(TAG, "MAIN_EVENT_RFID_ABSENT");
            bool allowed;
            // Ignore errors in ACL check; this is only performed to create a
            // log entry for offline stats reporting.
            acl_client_check_id(0, &allowed);
            relay_on_rfid_none();
            lcd_on_rfid_none();
            mqtt_on_rfid_none();
            break;
        }
        default:
            ESP_LOGI(TAG, "MAIN_EVENT_? %" PRId32, event_id);
            break;
    }
}

extern "C" void app_main() {
    // These values match the default event loop, other than task_name.
    const esp_event_loop_args_t event_loop_args = {
        .queue_size = CONFIG_ESP_SYSTEM_EVENT_QUEUE_SIZE,
        .task_name = "main",
        .task_priority = ESP_TASKD_EVENT_PRIO,
        .task_stack_size = ESP_TASKD_EVENT_STACK,
        .task_core_id = 0
    };
    ESP_ERROR_CHECK(esp_event_loop_create(&event_loop_args, &main_event_loop));
    cm_register_conf();
    acl_client_register_conf();
    momentary_register_conf();
    lcd_register_conf();
    cm_init();
    mqtt_init();
    lcd_init();
    relay_init();
    acl_client_init();
    momentary_init(&main_rfid_present,  &main_rfid_absent);
    rfid_init(&momentary_on_rfid_present, &momentary_on_rfid_absent);
    ESP_ERROR_CHECK(esp_event_handler_register_with(main_event_loop,
        MAIN_EVENT, ESP_EVENT_ANY_ID, main_event_handler, NULL));
}

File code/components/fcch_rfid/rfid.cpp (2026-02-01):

// Copyright 2024-2025 Stephen Warren <swarren@wwwdotorg.org>
// SPDX-License-Identifier: MIT

#include <string.h>

#include <driver/uart.h>
#include <driver/gpio.h>
#include <esp_log.h>

#include "fcch_connmgr/cm.h"
#include "fcch_connmgr/cm_util.h"
#include "fcch_rfid/rfid.h"

static const char *TAG = "rfid";

static const uart_port_t cm_rfid_uart_num = UART_NUM_1;
static const int cm_rfid_pin_txd = UART_PIN_NO_CHANGE;
static const int cm_rfid_pin_rxd = GPIO_NUM_13;
static const int cm_rfid_pin_rts = UART_PIN_NO_CHANGE;
static const int cm_rfid_pin_cts = UART_PIN_NO_CHANGE;
static const uint32_t rfid_fake_id = 12345;
static const TickType_t rfid_timeout_ticks = 2000 / portTICK_PERIOD_MS;
static const TickType_t rfid_fake_time_ticks = 10000 / portTICK_PERIOD_MS;

static rfid_callback_present *rfid_cb_present;
static rfid_callback_absent *rfid_cb_absent;

static void rfid_init_uart() {
    ESP_ERROR_CHECK(uart_driver_install(
        /* uart_num */ cm_rfid_uart_num,
        /* rx_buffer_size */ 256,
        /* tx_buffer_size */ 0,
        /* queue_size */ 0,
        /* uart_queue */ NULL,
        /* intr_alloc_flags */ 0));

    uart_config_t uart_config{};
    uart_config.baud_rate  = 9600;
    uart_config.data_bits  = UART_DATA_8_BITS;
    uart_config.parity     = UART_PARITY_DISABLE;
    uart_config.stop_bits  = UART_STOP_BITS_1;
    uart_config.flow_ctrl  = UART_HW_FLOWCTRL_DISABLE;
    uart_config.source_clk = UART_SCLK_DEFAULT;
    ESP_ERROR_CHECK(uart_param_config(cm_rfid_uart_num, &uart_config));

    ESP_ERROR_CHECK(uart_set_pin(cm_rfid_uart_num,
        cm_rfid_pin_txd, cm_rfid_pin_rxd, cm_rfid_pin_rts, cm_rfid_pin_cts));
}

static const int rfid_len = 12; // excluding STX, ETX

static uint32_t rfid_last_id;
static TickType_t rfid_last_id_time;
static bool rfid_fake_present;
static TickType_t rfid_fake_present_time;

static void rfid_http_action_present_fake_rfid() {
    rfid_fake_present = true;
    rfid_fake_present_time = xTaskGetTickCount();
}

static const char *rfid_http_action_present_fake_rfid_description() {
    assert(rfid_fake_id == 12345);
    assert(rfid_fake_time_ticks == 10000 / portTICK_PERIOD_MS);
    return "Present Fake RFID 12345 for 10s";
}

static void rfid_send_present(uint32_t rfid) {
    rfid_last_id = rfid;
    ESP_LOGD(TAG, "RFID present %lu", rfid);
    rfid_cb_present(rfid);
}

static void rfid_send_removed() {
    rfid_last_id = 0;
    ESP_LOGD(TAG, "RFID removed");
    rfid_cb_absent();
}

static void rfid_handle(uint32_t rfid) {
    if (rfid_fake_present)
        rfid = rfid_fake_id;

    if (rfid_last_id && rfid_last_id != rfid)
        rfid_send_removed();

    TickType_t now = xTaskGetTickCount();
    rfid_last_id_time = now;

    if (rfid == rfid_last_id)
        return;

    rfid_send_present(rfid);
}

static void rfid_check_timeout() {
    bool clear_rfid = false;

    TickType_t now = xTaskGetTickCount();

    if (rfid_fake_present) {
        TickType_t time_since_fake = now - rfid_fake_present_time;
        if (time_since_fake > rfid_fake_time_ticks) {
            rfid_fake_present = false;
            clear_rfid = true;
        }
    }

    if (rfid_last_id) {
        TickType_t time_since_rfid = now - rfid_last_id_time;
        TickType_t timeout = rfid_timeout_ticks;
        clear_rfid |= (time_since_rfid >= timeout);
    }

    if (!clear_rfid)
        return;

    rfid_send_removed();
}

static void rfid_handle_raw(char *buf) {
    uint8_t ibuf[rfid_len / 2];

    // String to int
    for (int i = 0; i < rfid_len; i += 2)
        ibuf[i / 2] =
            (cm_util_hex_char_to_uint(buf[i    ]) << 4) |
            (cm_util_hex_char_to_uint(buf[i + 1]) << 0);

    // CRC check
    uint8_t crc = 0;
    for (int i = 0; i < rfid_len / 2; i++) {
        crc ^= ibuf[i];
    }
    if (crc) {
        buf[rfid_len] = '\0';
        ESP_LOGW(TAG, "RFID bad CRC (%s, %02x)", buf, (unsigned int)crc);
        return;
    }

    uint32_t rfid = 0;
    for (int i = 1; i <= 4; i++)
        rfid = (rfid << 8) | ibuf[i];
    ESP_LOGD(TAG, "RFID present %lu", rfid);
    rfid_handle(rfid);
}

static void rfid_task(void *pvParameters) {
    char rfid_buf[rfid_len + 1]; // +1 is for NUL
    int rfid_buf_len = 0;
    TickType_t stx_time = 0;
    for (;;) {
        char rx_buf[1 + rfid_len + 1 + 1]; // STX, rfid data, ETX, NUL
        int rx_buf_len = uart_read_bytes(cm_rfid_uart_num,
            rx_buf, sizeof(rx_buf) - 1, 100 / portTICK_PERIOD_MS);
        if (rfid_fake_present)
            rfid_handle(rfid_fake_id);
        if (rx_buf_len) {
            rx_buf[rx_buf_len] = '\0';
            ESP_LOGD(TAG, "Raw TX (%s)", rx_buf);
        }
        for (int i = 0; i < rx_buf_len; i++) {
            char ch = rx_buf[i];
            if (ch == 0x02) {
                ESP_LOGD(TAG, "RFID starts now");
                rfid_buf_len = 0;
                stx_time = xTaskGetTickCount();
            } else if (ch == 0x03) {
                rfid_buf[rfid_buf_len] = '\0';
                ESP_LOGD(TAG, "RFID RX complete (%s)", rfid_buf);
                rfid_handle_raw(rfid_buf);
                rfid_buf_len = 0;
            } else if (rfid_buf_len >= rfid_len) {
                rfid_buf[rfid_buf_len] = '\0';
                ESP_LOGW(TAG, "RFID too long and no ETX (%s)", rfid_buf);
                rfid_buf_len = 0;
            } else {
                rfid_buf[rfid_buf_len++] = ch;
            }
        }
        if (rfid_buf_len) {
            TickType_t now = xTaskGetTickCount();
            TickType_t time_since_stx = now - stx_time;
            static const TickType_t max_rfid_recv_time =
                200 / portTICK_PERIOD_MS;
            if (time_since_stx >= max_rfid_recv_time) {
                rfid_buf[rfid_buf_len] = '\0';
                ESP_LOGW(TAG, "RFID RX timeout (%s)", rfid_buf);
                rfid_buf_len = 0;
            }
        }
        rfid_check_timeout();
    }
}

void rfid_init(
    rfid_callback_present *cb_present,
    rfid_callback_absent *cb_absent
) {
    ESP_LOGI(TAG, "rfid_init: start");
    rfid_cb_present = cb_present;
    rfid_cb_absent = cb_absent;
    rfid_init_uart();
    xTaskCreate(&rfid_task, "rfid", 4096, NULL, 5, NULL);
    ESP_LOGI(TAG, "rfid_init: done");
    cm_http_register_home_action(
        "rfid-present-fake-rfid",
        rfid_http_action_present_fake_rfid_description,
        rfid_http_action_present_fake_rfid
    );
}

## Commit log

2025-01-19 pcb: 20250118 version
    [rfid-v2.kicad_pcb, rfid-v2.kicad_sch]
2025-01-22 pcb: Add BOM - Bill Of Materials
2025-02-03 code: increase RFID hysteresis
    This avoids too much rapid toggling of rfid present/absent messages when
    the RFID is near the edge of detection range.
    [rfid.cpp]
2025-02-03 code: add GPIO toggle button
    This is useful for debugging equipment issues. Members shouldn't be able
    to abuse this functionality if an admin password is set, which it should
    be.
    [relay.cpp]
2025-02-05 pcb: add smaller PSU to BOM
2025-02-06 code: add button to force show RFIDs for debug
    This allows testing which RFIDs are detected, without having to change the
    configuration, save it, and reboot, possibly forgetting to turn it back
    off. This may be useful for debugging any issues with the reader.
    [lcd.cpp]
2025-02-08 Add a design for a mounting box.
    [fob-cage.scad, mounting.scad, render-2d.scad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]
2025-02-08 mounting: add offset ring
    This accounts for the thickness of the ends of the barrel nuts, and allows
    the layers to seal against the electrical box.
    [mounting.scad, render-2d.scad, render-3d.scad]
2025-02-11 pcb: add Gerber files
    [rfid-v2-B_Cu.gbr, rfid-v2-B_Mask.gbr, rfid-v2-B_Paste.gbr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]
2025-02-16 mounting: fix barrel nut cutout diameter
    Use the barrel nut size to calculate its cutout; no need to add in
    anything else.
    [mounting.scad]
2025-02-16 mounting: reduce barrel nut size
    This implements slight kerf correction, and stops the nuts falling out too
    easily during construction.
    [mounting.scad]
2025-03-01 code: change SPI mode
    On _some_ boards, mode 2 intermittently fails; the display won't
    initialize and nothing but black is displayed. This happens from 5-75% of
    the time on _some_ boards.
    The diagrams in the datasheet shows that mode 0 or mode 3 is correct. Many
    code examples for ST7789 use mode 0, but reading the diagrams in the
    datasheet looks like mode 3 to me, at least in the diagrams that clearly
    show the idle clock state; many are unclear. There are many references to
    using mode 3 in forums and bug reports on the Internet.
    With this change, I've booted the most problematic board 400 times without
    issue, with some reprogramming to use mode 2 in the middle which
    reproduced the problem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
    [lcd.cpp]
2026-01-10 OpenScad housing models for 3D Printing
    [allinone.scad, power_brick_bracket.scad]
2026-01-10 Case description
2026-01-10 mounting: rename 3d printed dir, add link in parent README
    [allinone.scad, power_brick_bracket.scad]
2026-01-13 mounting: equipment: add LightBurn files
    Not sure why I didn't add these before...
2026-01-19 pcb: update BOM with orderable part
2026-01-29 momentary: support milliseconds
    The user may specify time in seconds and/or milliseconds; the two values
    will be added together and used as the overall momentary time.
    Based-on-work-by: Nader Askari
2026-02-01 code: move fake RFID generation
    Move the "present fake RFID" code into the RFID reader module. This makes
    fake RFIDs work more like regular RFIDs. In turn, this allows it to
    interact correctly with momentary configuration.
    [main.cpp, rfid.cpp]
2026-03-16 pcb/code: v2a PCB
    The new PCB additionally supports the TTGO/Lilygo T-display v1.1 board,
    which has much better WiFi performance than the Ideaspark board.
    [rfid-v2-B_Cu.gbr, rfid-v2-B_Mask.gbr, rfid-v2-B_Paste.gbr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]
